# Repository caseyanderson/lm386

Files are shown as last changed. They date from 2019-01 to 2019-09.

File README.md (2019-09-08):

# LM386
Casey Anderson, 2018

## Overview

This repository provides a `Printed Circuit Board` (`PCB`) file and BOM for a 1-watt DC Audio Amplifier (`LM386N-4`)

## PCB

This double-sided `Pin Through Hole` (`PTH`) PCB was created in EAGLE

### BOM

Note: items without a `Manufacturer Part Number` are generic

* 1x LM386N-4
* 1x SWITCH SLIDE SPDT 200MA 30V, `EG1218`
* 1x CONN PWR JACK 2X5.5MM SOLDER, `PJ-102A`
* 2x CONN JACK STEREO 3.5MM, `SJ1-3523N`
* 1x POT 10kR 1/20W CARBON LOG, `PTV09A-4020F-A103`
* 1x 330R
* 1x 1000uF (Electrolytic)
* 2x 100uF (Electrolytic)
* 1x 10uF (Electrolytic)
* 1x 0.1uF (Ceramic)
* 1x 5mm LED

### Photo

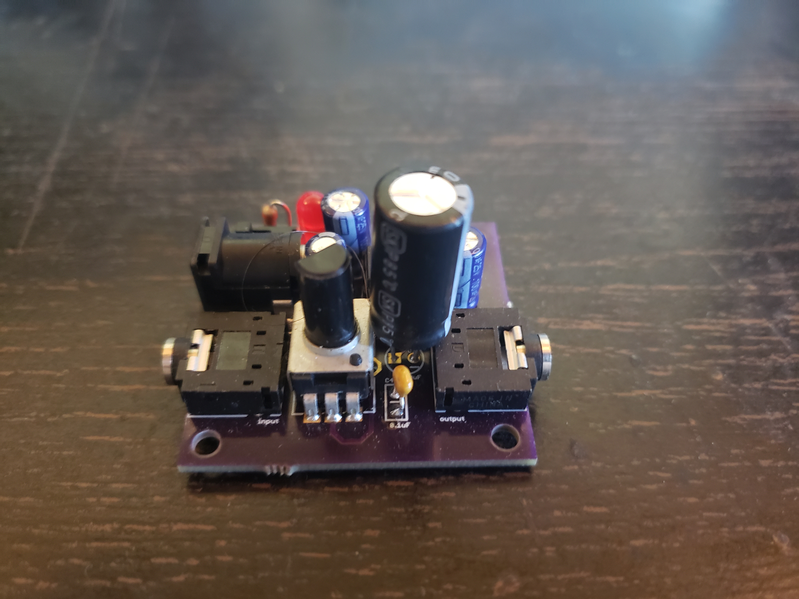
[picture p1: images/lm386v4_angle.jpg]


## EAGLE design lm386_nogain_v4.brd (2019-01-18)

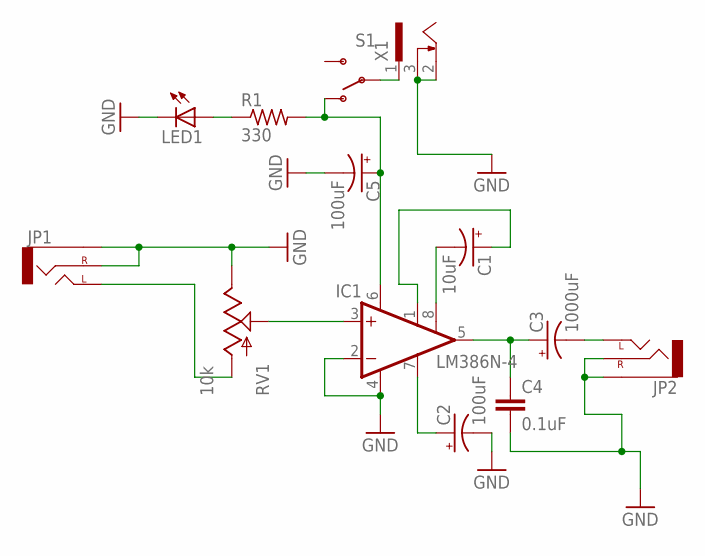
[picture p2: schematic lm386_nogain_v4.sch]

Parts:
C1: 10uF; CPOL-RADIAL-10UF-25V
C2: 100uF; CPOL-RADIAL-10UF-25V
C3: 1000uF; CPOL-RADIAL-10UF-25V
C4: 0.1uF; CAP-PTH-SMALL2
C5: 100uF; CPOL-RADIAL-100UF-25V
IC1: LM386N-4; DIL08
JP1, JP2: AUDIO-JACKPTH; AUDIO-JACK
LED1: LED5MM
R1: 330; 0204V
RV1: 10k; ALPS_POT
S1: SWITCH-SPDTPTH_LOCK; SWITCH-SPDT_LOCK.007S
X1: SCD-014A; SCD-014-A

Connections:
GND: C2.2 (-), C4.2, C5.2 (-), IC1.2 (-IN), IC1.4 (GND), JP1.RING (RIGHT), JP1.SLEEVE, JP2.RING (RIGHT), JP2.SLEEVE, LED1.K (C), RV1.P$1 (E), X1.2, X1.3
unnamed: JP1.TIP (LEFT), RV1.P$3 (A)
unnamed: IC1.3 (+IN), RV1.P$2 (S)
unnamed: S1.2, X1.1
unnamed: C5.1 (+), IC1.6 (VS), R1.2, S1.1 (O)
unnamed: C1.1 (+), IC1.1 (GAIN)
unnamed: C1.2 (-), IC1.8 (GAIN)
unnamed: C2.1 (+), IC1.7 (BYPASS)
unnamed: C3.1 (+), C4.1, IC1.5 (OUT)
unnamed: LED1.A, R1.1
unnamed: C3.2 (-), JP2.TIP (LEFT)

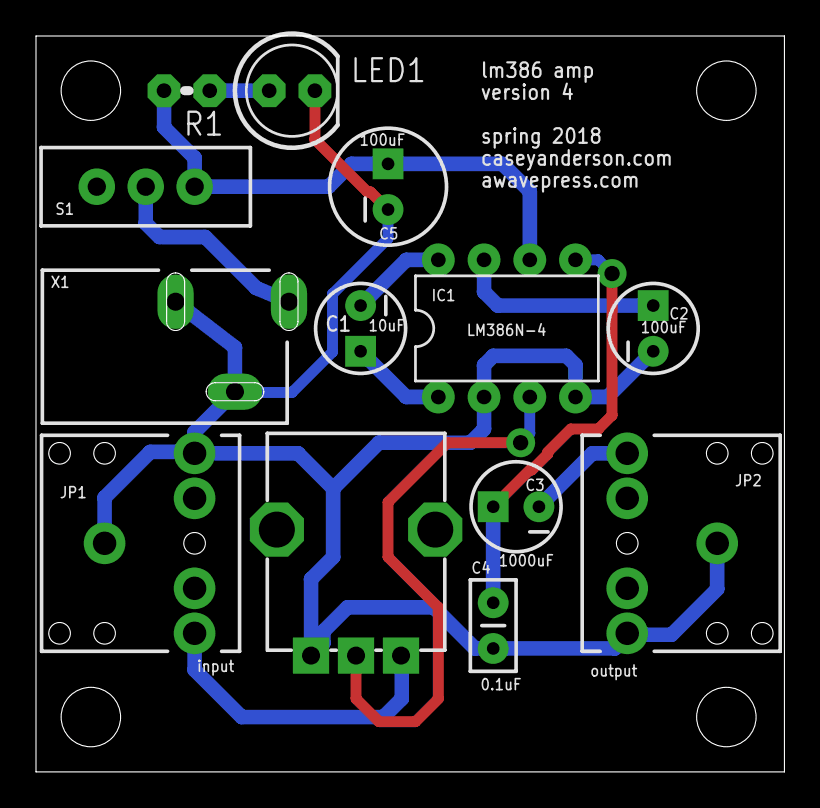
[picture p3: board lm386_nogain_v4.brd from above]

Board: 2 copper layers, 41.6 x 40.9 mm, 17 parts (0 on the bottom side), 11 nets.

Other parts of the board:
U$1, U$2, U$3, U$4: STAND-OFF

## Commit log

2019-01-18 putting .brd and .sch in this repo
    [lm386_nogain_v4.brd, lm386_nogain_v4.sch]
2019-09-08 adds .gitignore, README, and a photo of the pcb

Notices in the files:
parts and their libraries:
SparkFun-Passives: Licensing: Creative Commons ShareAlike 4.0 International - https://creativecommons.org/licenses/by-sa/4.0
